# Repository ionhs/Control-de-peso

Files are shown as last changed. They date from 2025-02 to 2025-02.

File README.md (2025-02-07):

# PISU KONTROLA / CONTROL DE PESO

 

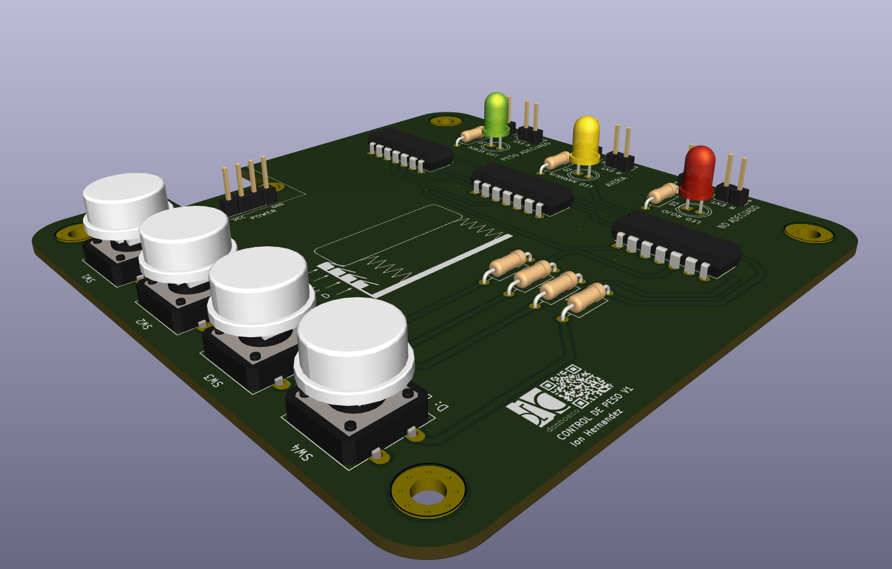
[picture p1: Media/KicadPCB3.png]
KiCad Imagen PCB


Este es el primer circuito que monta el alumnado de [Don Bosco](https://www.donbosco.eus/elektronika-mantentzen-lana/) en el ciclo de grado superior de Mantenimiento Electrónico. En vez de montar sobre una PCB, el alumnado lo monta sobre una protoboard.

Esto es parte del primer reto, en el que el alumnado sin ningún conocimiento previo ha de diseñar un sistema digital de control de peso con **4 sensores**. Cuanto más peso haya, se irán pulsando más botones hasta alcanzar la cantidad de peso optima, en el que se encenderá un **led verde.** En el caso que el peso no sea adecuado (por exceso o por defecto) se encenderá un **led rojo**. En el caso que la señal de entrada de los botones no sea lógica, se considerará que hay una avería que se indicará mediante un **led naraja**.

En este reto se busca que alumnado adquiera competencias y conocimientos en:

- Señales digitales 1/0 de entrada y de salida.

- Puertas lógicas (not, and, or...).

- Ecuaciones lógicas.

- Método de simplificación de ecuaciones con Karnaugh.

- Montaje y simulación de circuitos con puertas lógicas.

- Mantenimiento de circuitos con puertas lógicas.

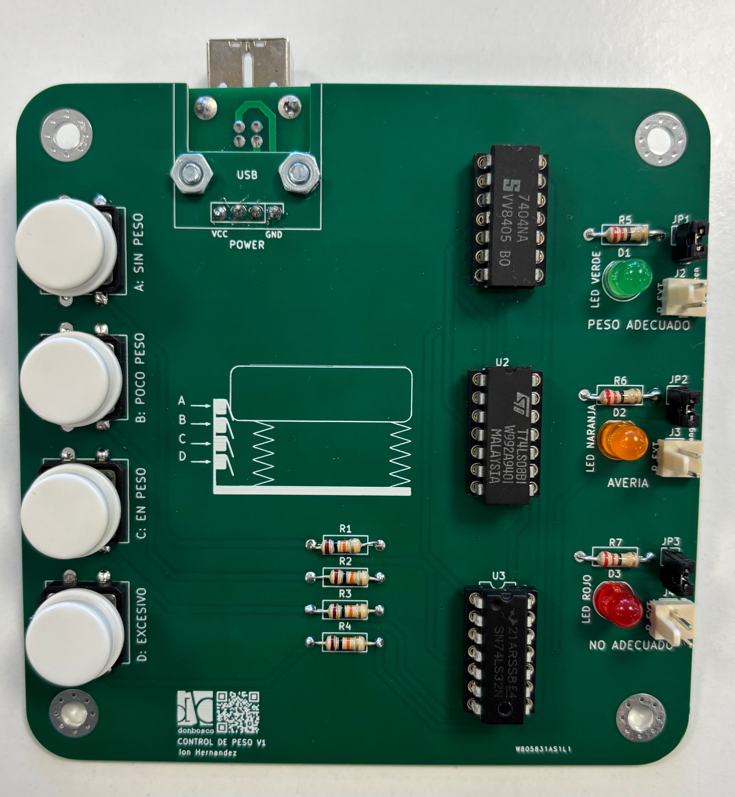
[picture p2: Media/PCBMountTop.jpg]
KiCad Imagen PCBMount


El diseño ha sido realizado en [KiCad](https://www.kicad.org/), un software **open source**. Esto permite que cualquiera pueda replicar el proyecto o modificarlo según sus necesidades, facilitando su adaptación a otros usos educativos o personales.

## Puesta en marcha

Para hacer una demostración y la puesta en marcha hay que seguir los siguientes pasos:

1. Dejar la placa sobre la mesa, sin que ningún objeto metálico tenga contacto por la parte de abajo.

2. Mediante un cable usb conectar la placa a una fuente de alimentación usb o un portátil.

En este momento la placa ya es funcional por lo que se puede hacer la siguiente demostración de funcionamiento:

1. Pulsar el botón A y luego A y B a la vez para demostrar que con poco peso se enciende el diodo led de peso no adecuado.

2. Pulsar los botones A, B y C a la vez para demostrar que con peso adecuado se enciende el diodo led de peso adecuado.

3. Pulsar los cuatro botones a la vez para demostrar que con peso excesivo se enciende el diodo led de peso no adecuado.

4. Para demostrar la avería hay que pulsar alguna de las combinaciones imposibles como pulsar sólo B, sólo C, sólo D, sólo B y C a la vez, sólo B y D a la vez, sólo C y D a la vez o sólo B y C y D a la vez. En estos casos se encenderá avería y puede que algunos de los otros dos diodos leds. Como se enciende avería sólo se hace caso a la avería por lo que los otros led diodos no avisarían de nada.

Se puede mostrar la parte de electrónica analógica del reto. Para ello habría que tener una placa con resistencias en serie y paralelo que den 220 ohms de resistencia equivalente. Para conectarla hay que seguir estos pasos:

1. Quitar el jumper (JP1, JP2 o JP3) de la la resistencia interna de la placa que se quiere anular para conectar una equivalente por fuera.

2. Conectar al conector (J2, J3 o J4) la placa de resistencias equivalentes.

3. Probar los puntos 1, 2, 3, 4 de la demostración de funcionamiento.

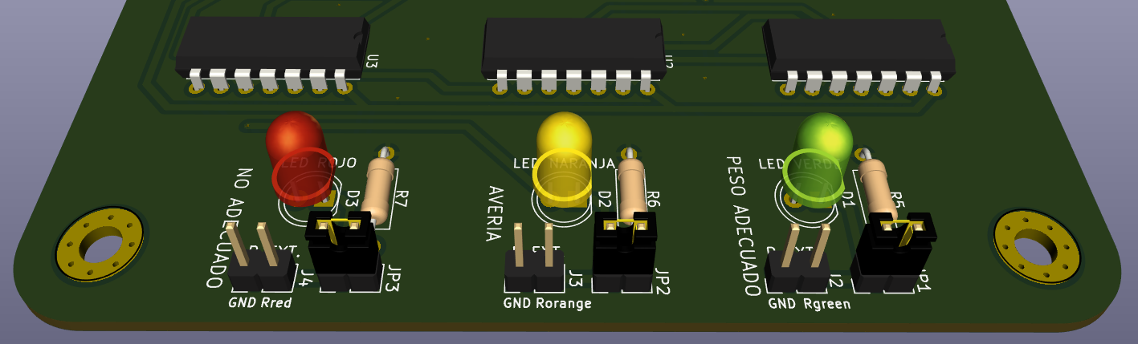
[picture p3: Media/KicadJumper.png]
KiCad Imagen Jumper
4. 

## Puntos a mejorar

La placa de alimentación usb hay que ponerla por la parte de abajo para que vcc y gnd estén adecuadamente posicionada. Si se quiere que el USB esté por encima de la PCB habría que modificar el layout dándole la vuelta a la placa de alimentación USB y cambiando el routeo de los dos pads.

Además como mejora se puede diseñar una PCB de una fuente de alimentación de 5v. En la salida se pondría una placa de alimentación USB y mediante un cable, se podría conectar la placa de alimentación, al circuito del control de peso.

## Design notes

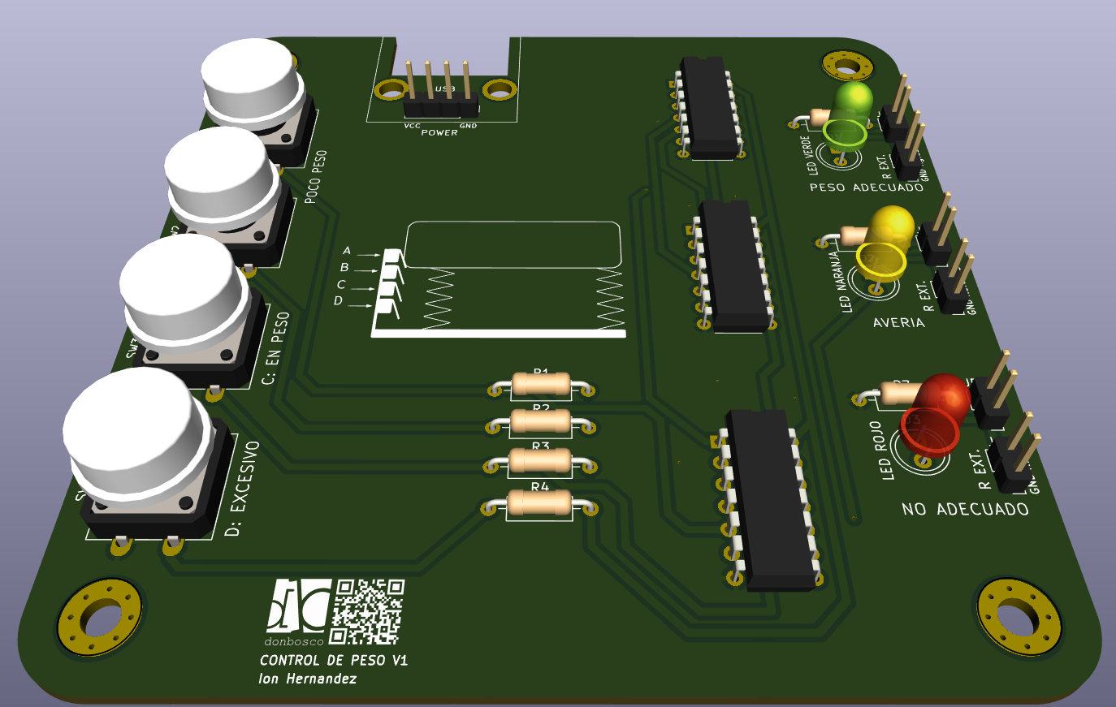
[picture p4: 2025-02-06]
Media/KicadPCB2.png

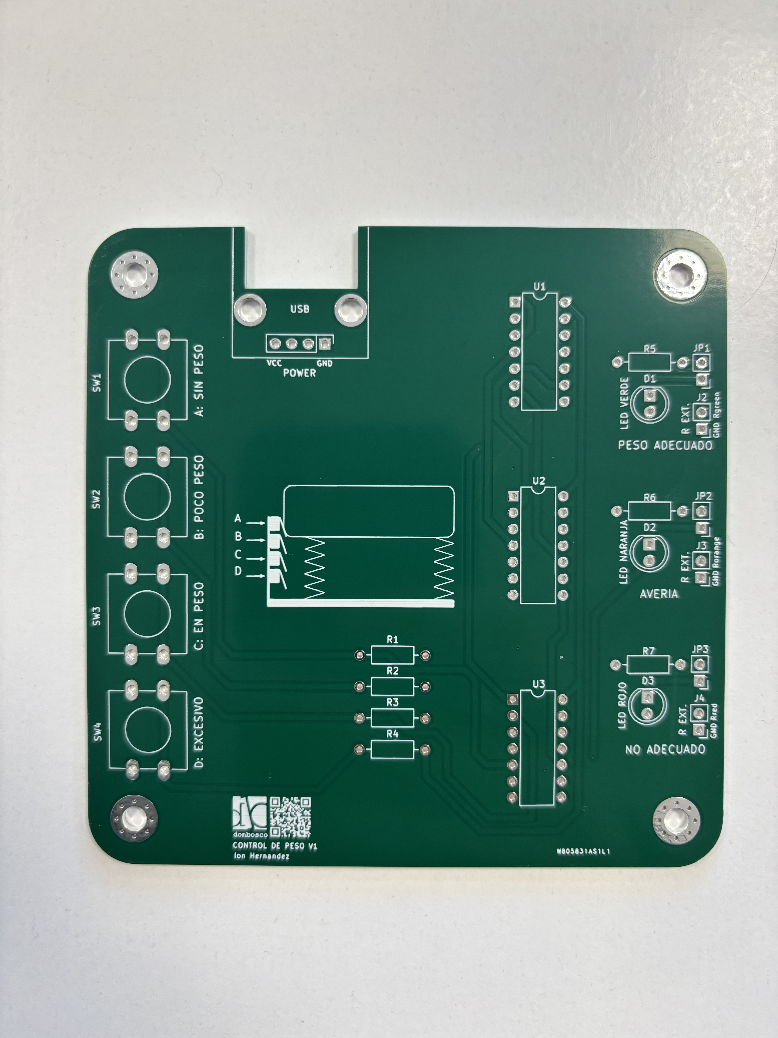
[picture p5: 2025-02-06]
Media/PCBTop.jpg

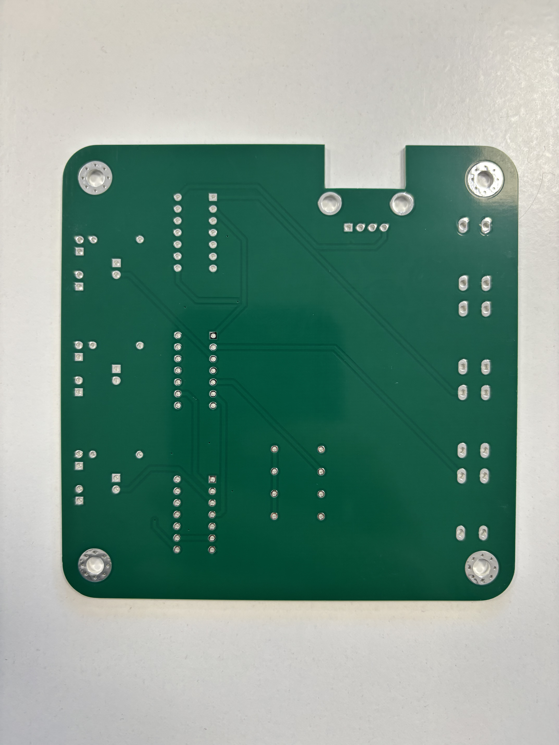
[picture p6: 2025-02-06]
Media/PCBBack.jpg

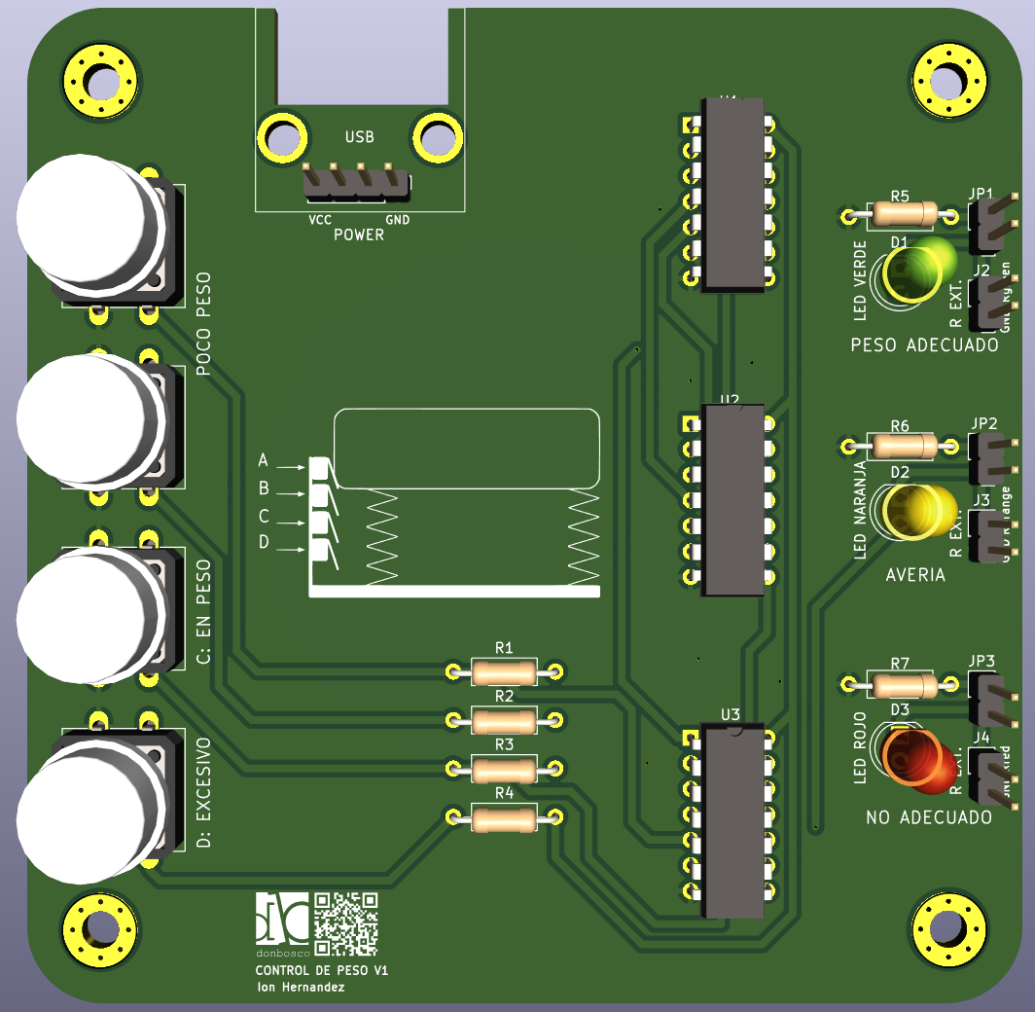
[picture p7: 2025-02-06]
Media/KicadPCB1.png

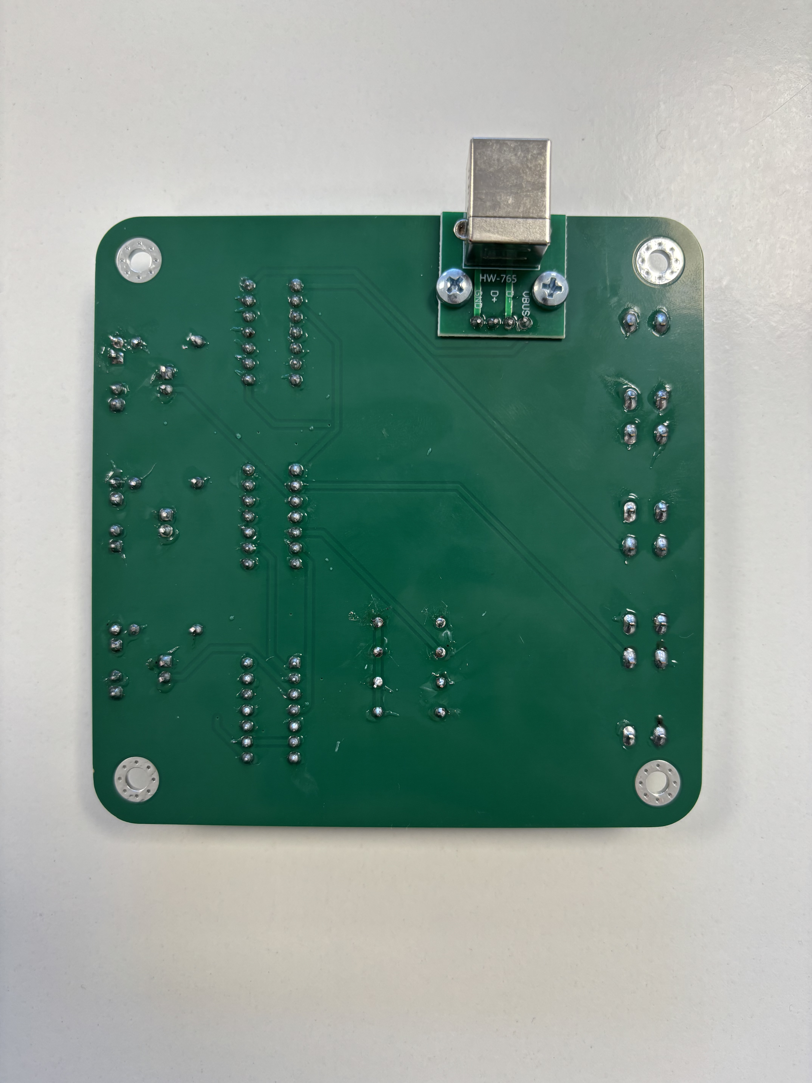
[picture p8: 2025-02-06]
Media/PCBMountBack.jpg

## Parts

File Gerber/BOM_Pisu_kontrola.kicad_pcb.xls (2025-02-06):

designator | quantity | value | pack | mpn | mount_type | Shop
D1 | 1 | LED VERDE | LED_D5.0mm |  | tht | https://es.aliexpress.com/item/1005005708510866.html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
D2 | 1 | LED NARANJA | LED_D5.0mm |  | tht | https://es.aliexpress.com/item/1005005708510866.html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
D3 | 1 | LED ROJO | LED_D5.0mm |  | tht | https://es.aliexpress.com/item/1005005708510866.html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
J1 | 1 | Power | USB -1x04_P2.54mm |  | tht | https://es.aliexpress.com/item/32973181162.html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
J2, J3, J4, JP1, JP2, JP3 | 6 | Conn_01x02 | PinHeader_1x02_P2.54mm_Vertical |  | tht | https://es.aliexpress.com/item/32973181162.html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
R1, R2, R3, R4 | 4 | 10k | R_Axial_DIN0207_L6.3mm_D2.5mm_P10.16mm_Horizontal |  | tht | https://es.aliexpress.com/item/1005002852691563.html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
R5, R6, R7 | 3 | 220 | R_Axial_DIN0207_L6.3mm_D2.5mm_P10.16mm_Horizontal |  | tht | https://es.aliexpress.com/item/1005002852691563.html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
SW1, SW2, SW3, SW4 | 4 | SW_Push | SW_PUSH-12mm |  | tht | https://es.aliexpress.com/item/1005002535796122.html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
U1 | 1 | 74LS04 | DIP-14_W7.62mm |  | tht | https://es.aliexpress.com/item/1005006102555449.html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
U2 | 1 | 74LS08 | DIP-14_W7.62mm |  | tht | https://es.aliexpress.com/item/1005006102555449.html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
U3 | 1 | 74LS32 | DIP-14_W7.62mm |  | tht | https://es.aliexpress.com/item/1005006102555449.html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
USB | 1 | Square USB | Micro Mini USB A macho |  | tht | https://es.aliexpress.com/item/4001146122421.html
Zocalo U1,U2,U3 (opcional) | 3 | DIP-14 | DIP-14_W7.62mm |  | tht | https://es.aliexpress.com/item/1005006783013959.html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

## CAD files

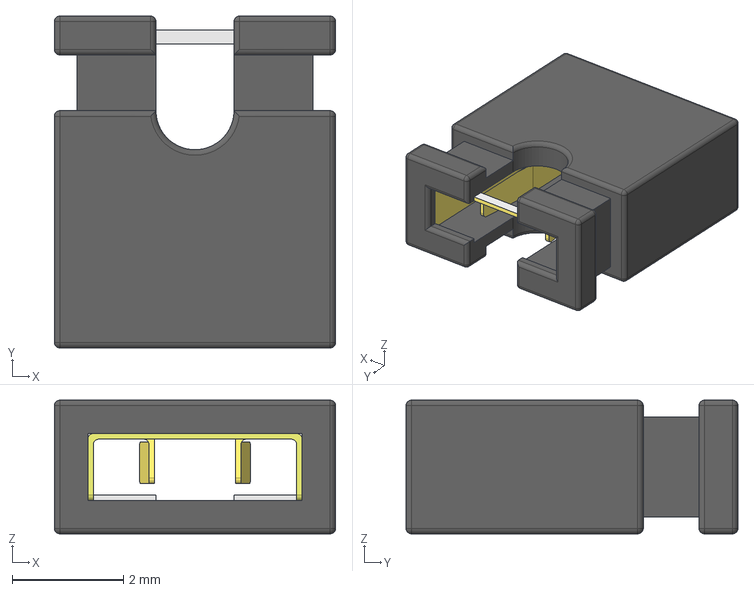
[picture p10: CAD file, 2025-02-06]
3D/Jumper Assembly.STEP
5.05 x 5.96 x 2.40 mm
Jumper Body
Metal Insert

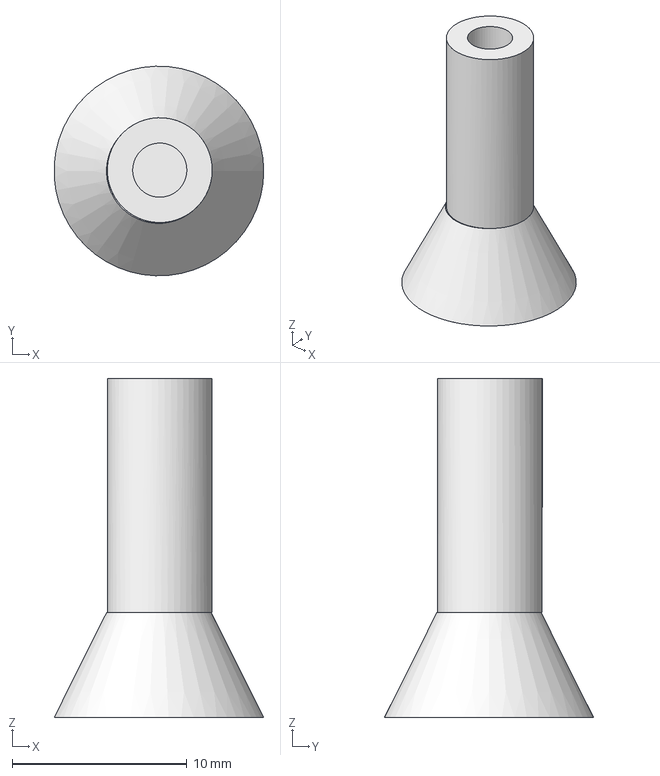
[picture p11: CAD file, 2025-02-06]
3D/Oina.FCStd
12.0 x 12.0 x 19.4 mm

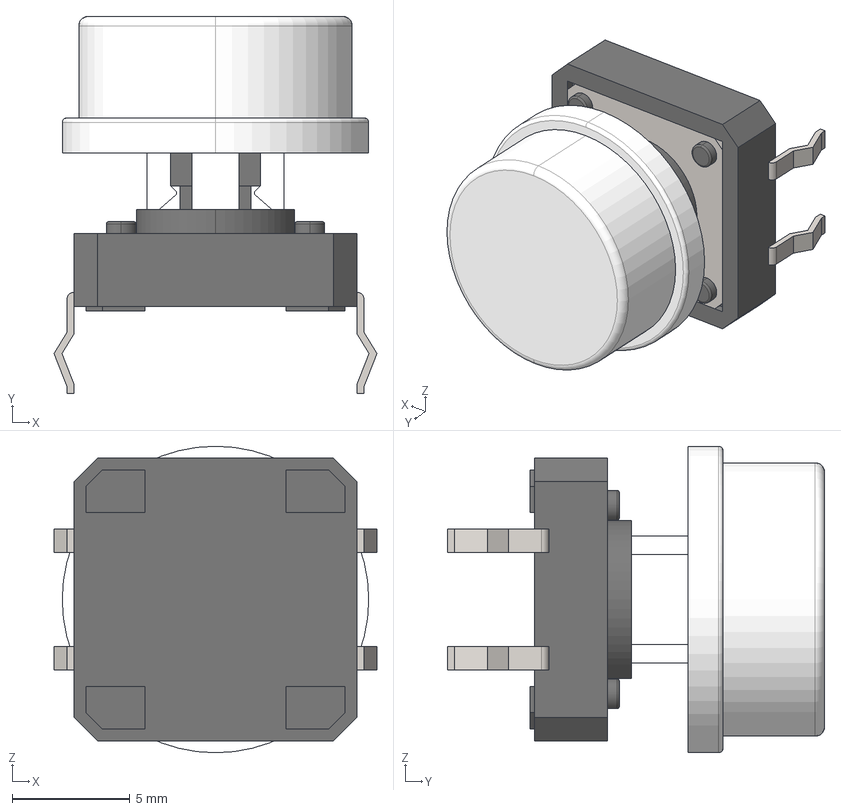
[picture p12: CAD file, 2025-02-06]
3D/12mm Push Button with Cap.STEP
13.7 x 16.0 x 13.0 mm
12mm Push Button Cap
12mm Push Button
12mm Push Button001
12mm Push Button002
12mm Push Button003
12mm Push Button004
12mm Push Button005
12mm Push Button006

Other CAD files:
3D/Oina-Fusion.stl

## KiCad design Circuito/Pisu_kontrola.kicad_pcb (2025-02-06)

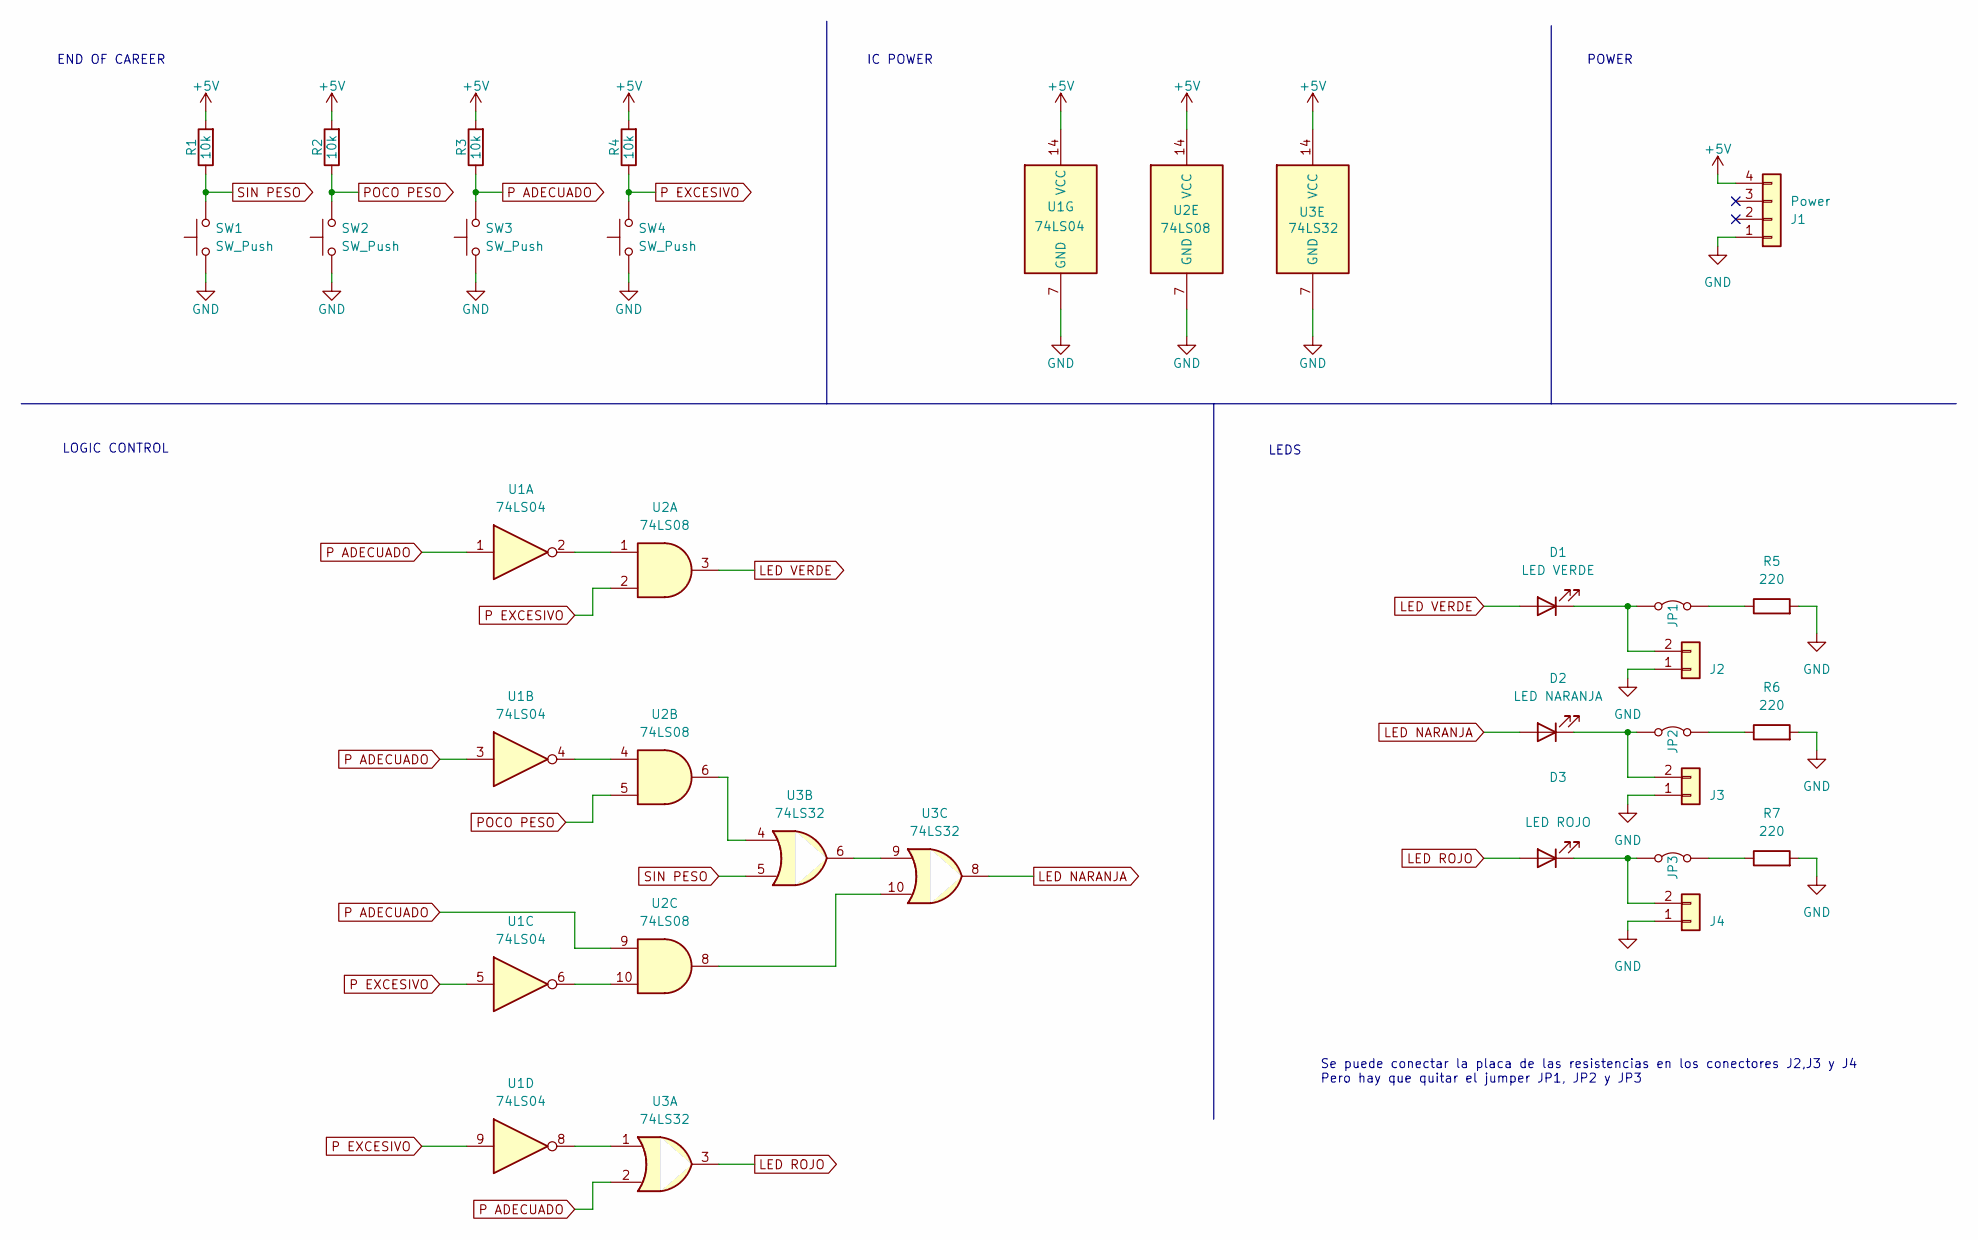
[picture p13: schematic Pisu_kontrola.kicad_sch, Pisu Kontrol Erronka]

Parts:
D1: LED VERDE; LED_D5.0mm
D2: LED NARANJA; LED_D5.0mm
D3: LED ROJO; LED_D5.0mm
J1: Power; USB -1x04_P2.54mm
J2, J3, J4: Conn_01x02; PinHeader_1x02_P2.54mm_Vertical
JP1, JP2, JP3: Jumper_2_Bridged; PinHeader_1x02_P2.54mm_Vertical
R1, R2, R3, R4: 10k; R_Axial_DIN0207_L6.3mm_D2.5mm_P10.16mm_Horizontal
R5, R6, R7: 220; R_Axial_DIN0207_L6.3mm_D2.5mm_P10.16mm_Horizontal
SW1, SW2, SW3, SW4: SW_Push; SW_PUSH-12mm
U1: 74LS04; DIP-14_W7.62mm
U2: 74LS08; DIP-14_W7.62mm
U3: 74LS32; DIP-14_W7.62mm

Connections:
+5V: J1.4, R1.2, R2.2, R3.2, R4.2, U1.14 (VCC), U2.14 (VCC), U3.14 (VCC)
GND: J1.1, J2.1, J3.1, J4.1, R5.2, R6.2, R7.2, SW1.1, SW2.1, SW3.1, SW4.1, U1.7 (GND), U2.7 (GND), U3.7 (GND)
LED NARANJA: D2.2 (A), U3.8
LED ROJO: D3.2 (A), U3.3
LED VERDE: D1.2 (A), U2.3
unnamed: D1.1 (K), J2.2, JP1.1 (A)
unnamed: D2.1 (K), J3.2, JP2.1 (A)
unnamed: D3.1 (K), J4.2, JP3.1 (A)
unnamed: JP1.2 (B), R5.1
unnamed: JP2.2 (B), R6.1
unnamed: JP3.2 (B), R7.1
unnamed: U1.2, U2.1
unnamed: U1.4, U2.4
unnamed: U1.6, U2.10
unnamed: U1.8, U3.1
unnamed: U2.6, U3.4
unnamed: U2.8, U3.10
unnamed: U3.6, U3.9
P ADECUADO: R3.1, SW3.2, U1.1, U1.3, U2.9, U3.2
P EXCESIVO: R4.1, SW4.2, U1.5, U1.9, U2.2
POCO PESO: R2.1, SW2.2, U2.5
SIN PESO: R1.1, SW1.2, U3.5

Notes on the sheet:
Se puede conectar la placa de las resistencias en los conectores J2,J3 y J4 Pero hay que quitar el jumper JP1, JP2 y JP3
LEDS
IC POWER
POWER
LOGIC CONTROL
END OF CAREER

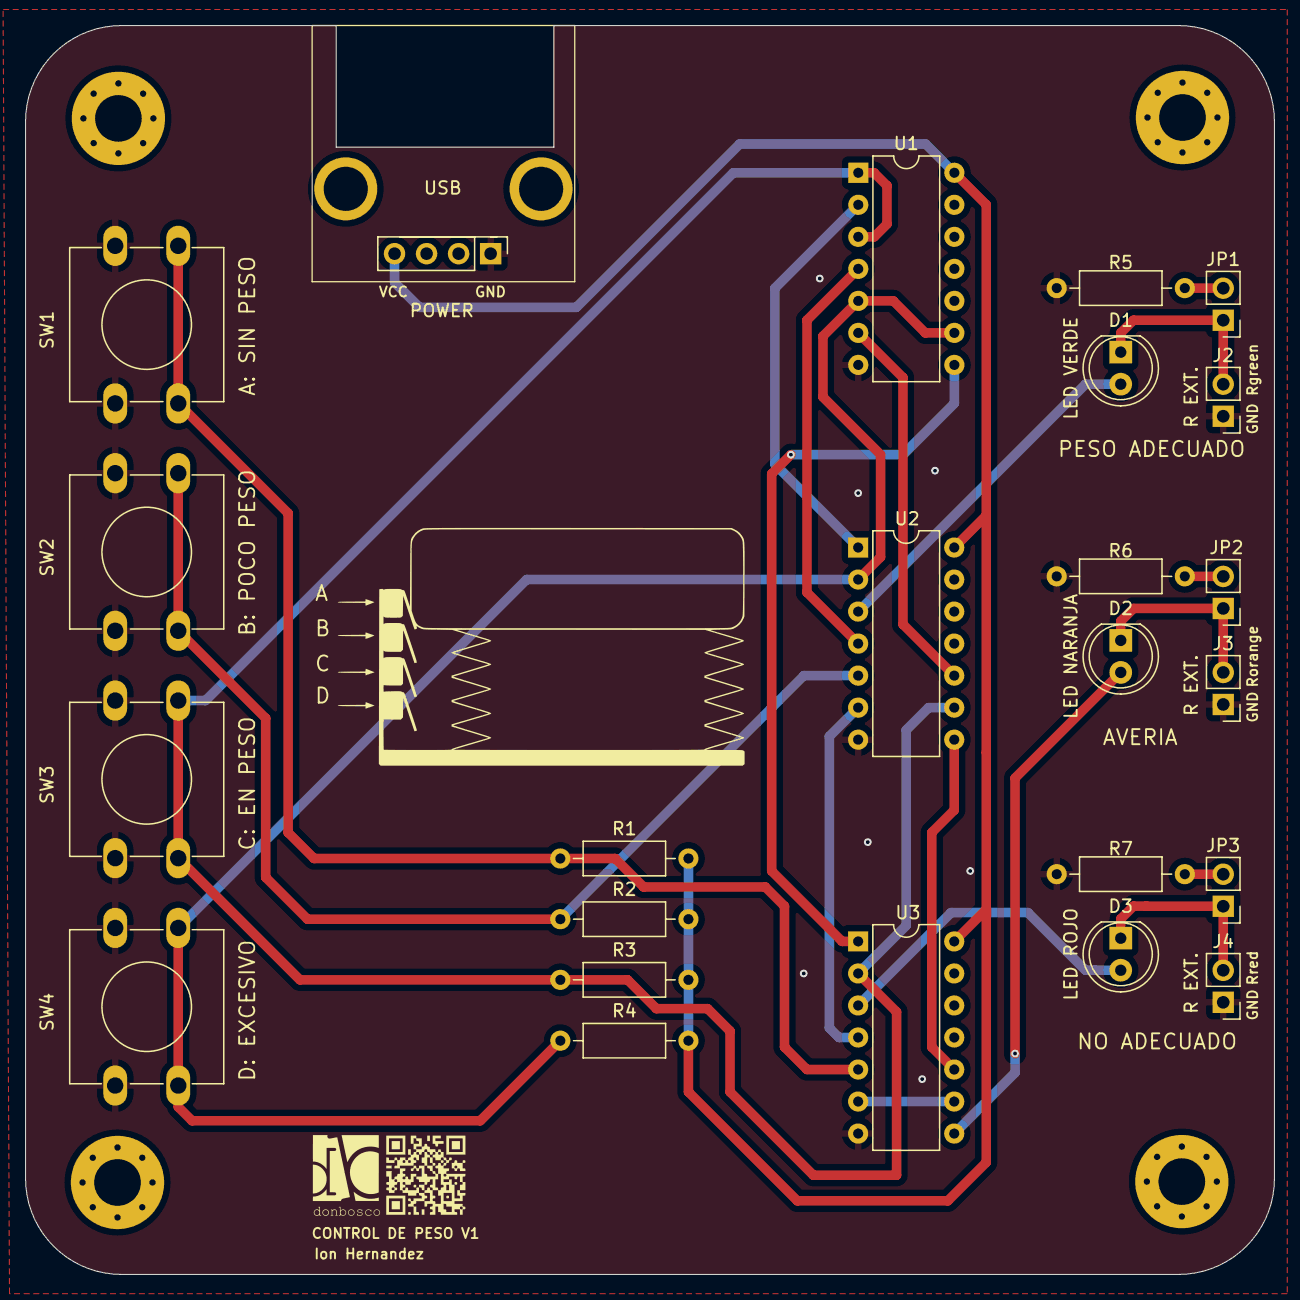
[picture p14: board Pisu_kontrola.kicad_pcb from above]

Board: 2 copper layers, 99.1 x 99.1 mm, 24 parts (0 on the bottom side), 22 nets.

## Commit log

2025-02-06 Inicio del repositorio en local
    [12mm Push Button with Cap.STEP, BOM_Pisu_kontrola.kicad_pcb.xls, Jumper Assembly.STEP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]
2025-02-07 Readme actualización de enlaces

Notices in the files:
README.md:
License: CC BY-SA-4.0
